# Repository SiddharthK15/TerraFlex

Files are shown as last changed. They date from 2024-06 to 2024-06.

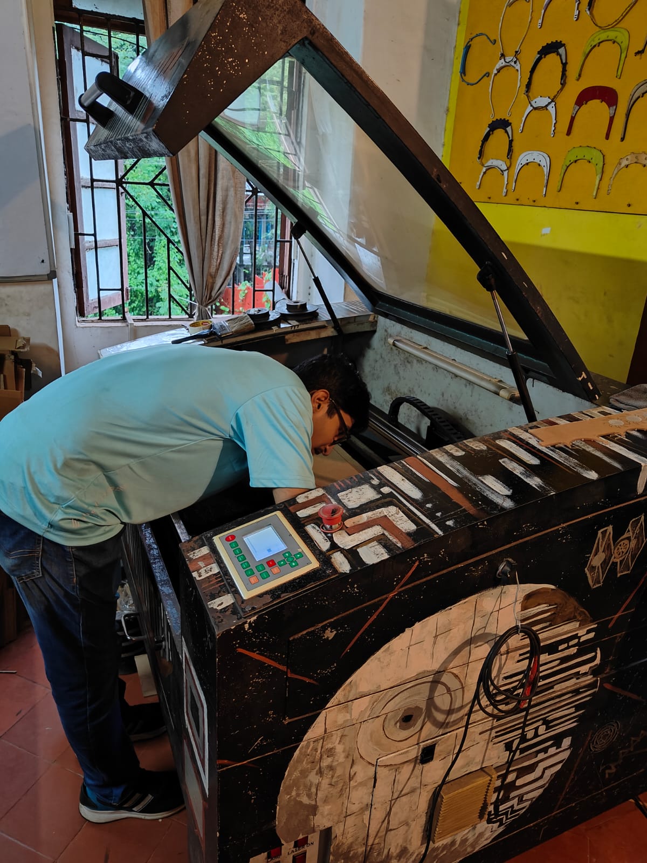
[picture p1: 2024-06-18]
Photos and Videos/Laser Cutting Plywood Testing Track.jpg

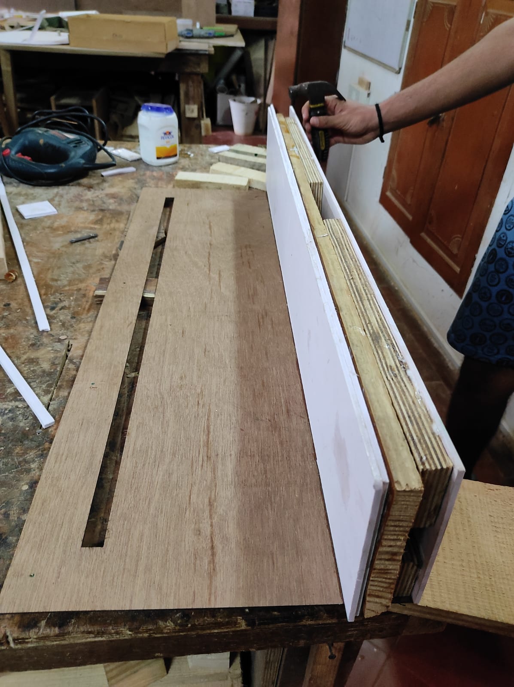
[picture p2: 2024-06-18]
Photos and Videos/Test track_one side.jpg

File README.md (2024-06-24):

Problem statement - Our project introduces an innovative wheel designed to enhance performance across both smooth and rough terrains. Traditional wheels often struggle with stability and traction on uneven surfaces, leading to discomfort and reduced efficiency. 

Solution - Our wheel addresses these challenges by integrating adaptive spring mechanisms that allow the wheel to dynamically adjust to surface irregularities. TerraFlex promises a smoother ride experience while maintaining efficiency on paved roads. 

Objectives - Create a wheel that is equally efficient on smooth roads and rough terrain, Ensure stability by using spring suspensions inside the wheel, as opposed to spokes, Avoid punctures as the wheel is airless

Licensing information

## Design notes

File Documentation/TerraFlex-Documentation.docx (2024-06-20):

Problem statement

Our project introduces an innovative wheel designed to enhance performance across both smooth and rough terrains. Traditional wheels often struggle with stability and traction on uneven surfaces, leading to discomfort and reduced efficiency.

Solution

Our wheel addresses these challenges by integrating spring mechanisms that allow the wheel to dynamically adjust to surface irregularities. TerraFlex provides a smoother experience while maintaining efficiency on paved roads.

Objectives

- Create a wheel that is equally efficient on smooth roads and rough terrain.
- Ensure stability by using spring suspensions inside the wheel, as opposed to spokes.
- Avoid punctures as the wheel is airless

Final Idea

At our 7 day residency at Maker’s Asylum in Goa, we learnt various skills like woodworking, laser cutting and 3D printing. These skills were essential to make the wheel, since our project is purely mechanical with no coding involved.

Our final project is a scale model 150mm diameter wheel with alternating spring and solid sections. The spring sections will absorb any terrain irregularities like rocks and broken ground, and the solid sections will maintain the same regular rotation on smooth roads. Most of the wheel is 3D printed. The 3D printed part sizes can be obtained from the CAD files “Assembly final” or “Wheel made as one.”

Constraints

- The materials used to make the solid sections must be able to withstand the weight of the car, along with jerks during motion.
- The springs must compress adequately to allow smooth motion on rough terrain
- The spring sections must not cause bouncy motion on smooth roads.
- For our prototype, the weight must be accurately simulated as 50-70N

Chronological Progress

Pre-residency (online)

We brainstormed different techniques and mechanisms which can help the wheel maintain stability without having to rely on external vehicle suspension. We took inspiration from the PATS wheel and NASA’s airless wheels for Mars missions. After researching different types of past innovative wheel designs, we decided on creating a wheel with alternating spring sections and solid sections. We designed the CAD models of the wheel on Fusion 360 during online team meetings.

Residential

We designed the testing track to test our wheel prototype on. We finalized on a 850mm length track with a slider and block attached above the wheel to act as the weight of the car. After comparing the ratio of the size of our prototype to the size of an actual wheel, we determined the weight acting on the wheel to be 70N. We then laser-cut the first-version of our bracket for the test track, and cardboard side plates for our side-track and tested the wood block as a slider. After multiple trials, we determined the slider dimensions to be 20mm x 70mm x 18mm. We then got our CAD models 3D printed with ABS, TPU and PLA. We assembled the wheel using super glue to stick the 3D printed parts together. We printed 5 different inner pieces and tested each one of them. We finally decided on using a Large Curve piece. Our final design used 8 solid sections and 8 spring sections with a total of 16 20mm springs.

Materials Used

- 4 x Cylinder - 3D Printed ABS - diameter 30mm and thickness 35mm. With a hole in the middle.
- 24 x Springs - length of 20mm and outer diameter of 10mm. Wire thickness 0.5mm
- 3D printing material - PLA 168g and 109g TPU and 304g ABS
- 850mm x 300mm Plywood with thickness 3mm with a 750mm x 17 mm slit for side plate
- 850mm x 300mm clear acrylic with thickness 1.7mm with a 750mm x 17 mm slit for side plate
- 20mm x 70mm x 160mm Plywood block as slider
- 150mm x 850mm - Sunboard x 2 for base of track

Project Mind Map

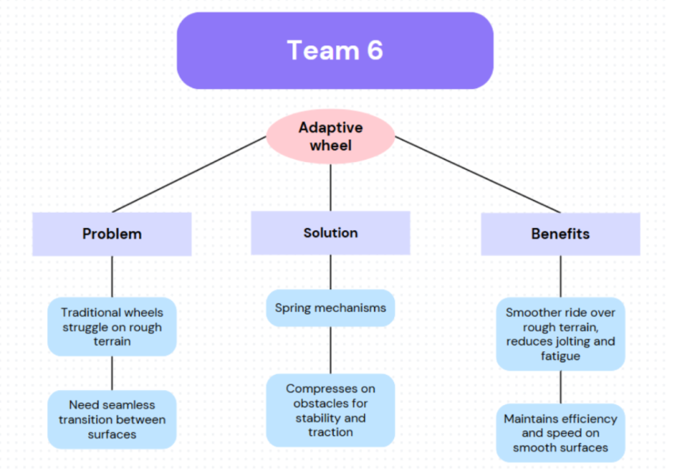
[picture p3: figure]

Block Diagram based on objectives

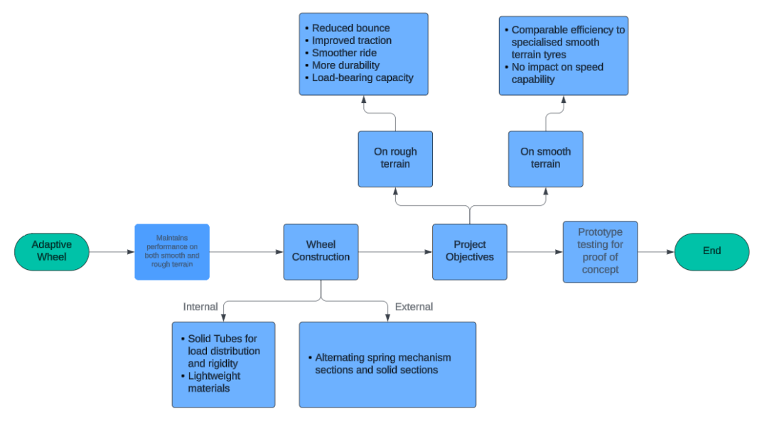
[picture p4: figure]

Final Wheel Model

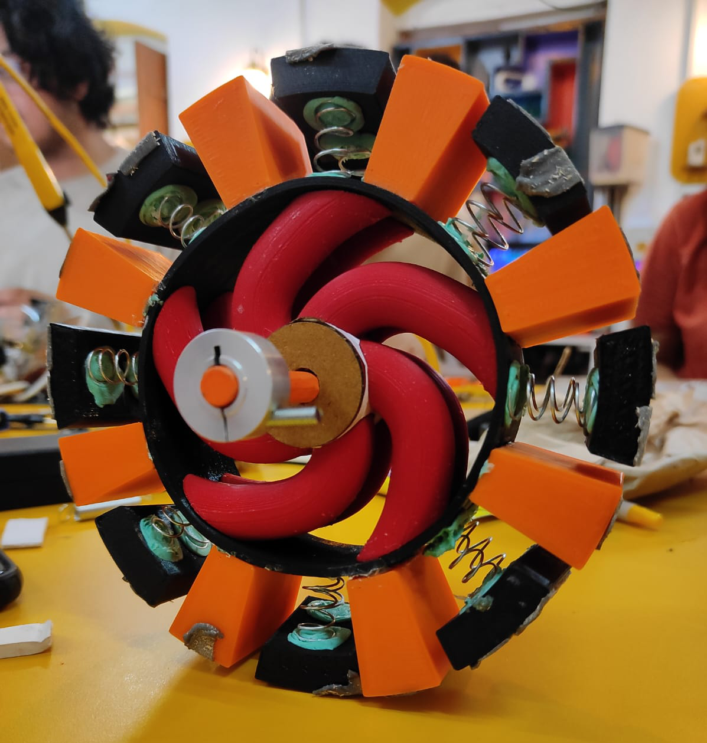
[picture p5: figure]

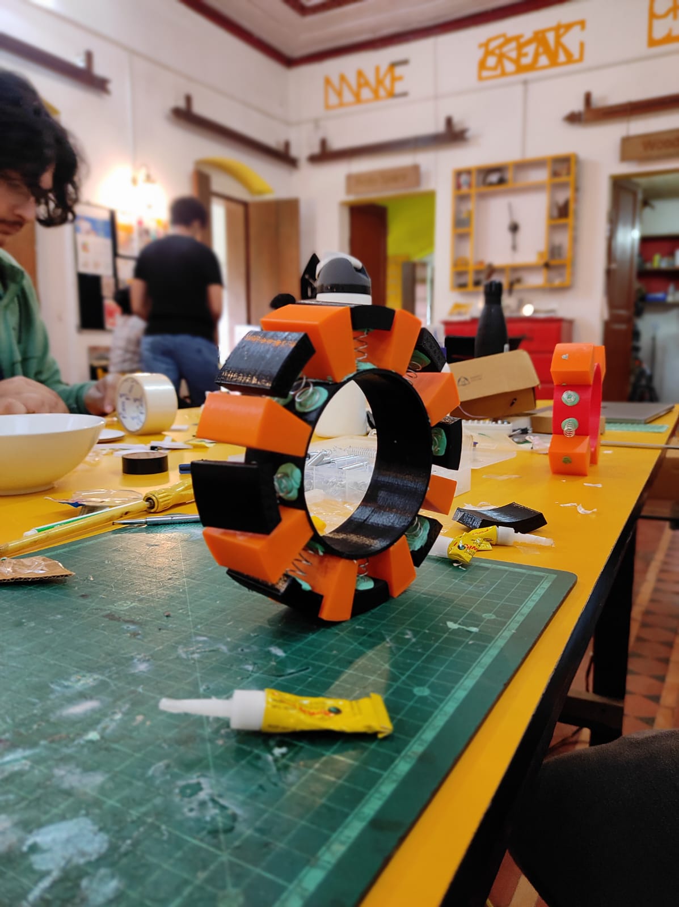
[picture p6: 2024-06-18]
Photos and Videos/Final outer layer.jpg

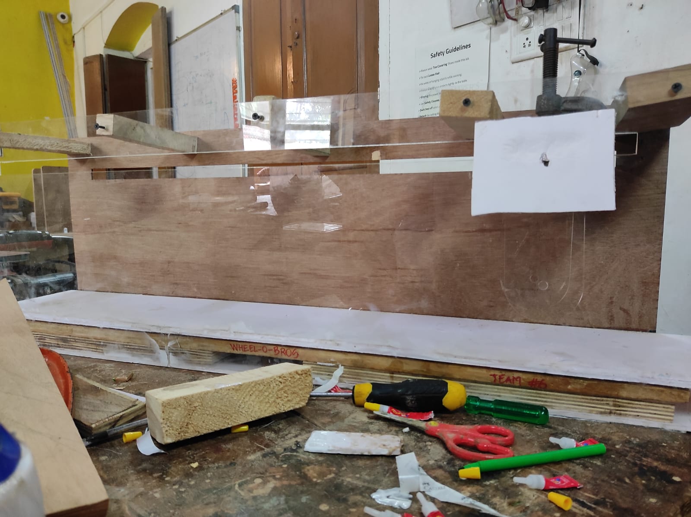
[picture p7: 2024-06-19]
Photos and Videos/Side track final front view.jpg

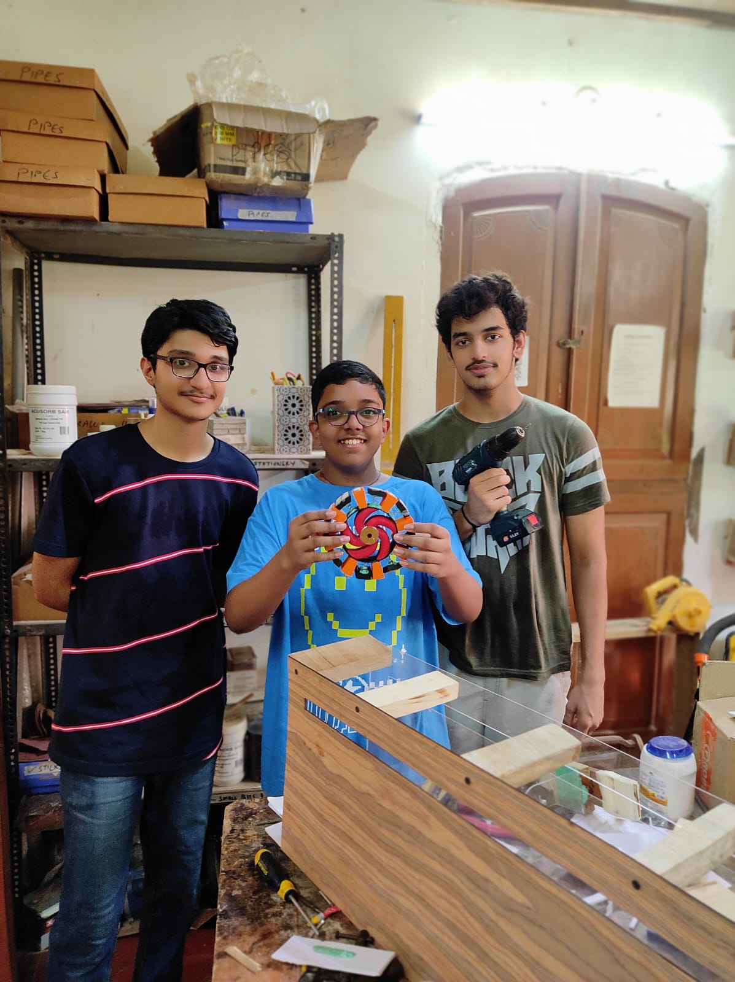
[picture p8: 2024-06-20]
Photos and Videos/Team Photo.jpg

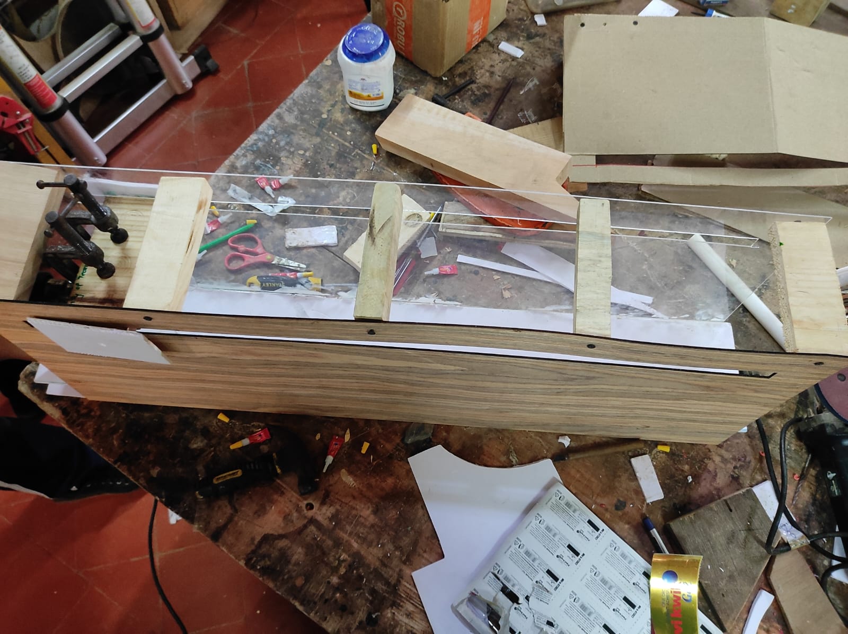
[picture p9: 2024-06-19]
Photos and Videos/Side track final Top view.jpg

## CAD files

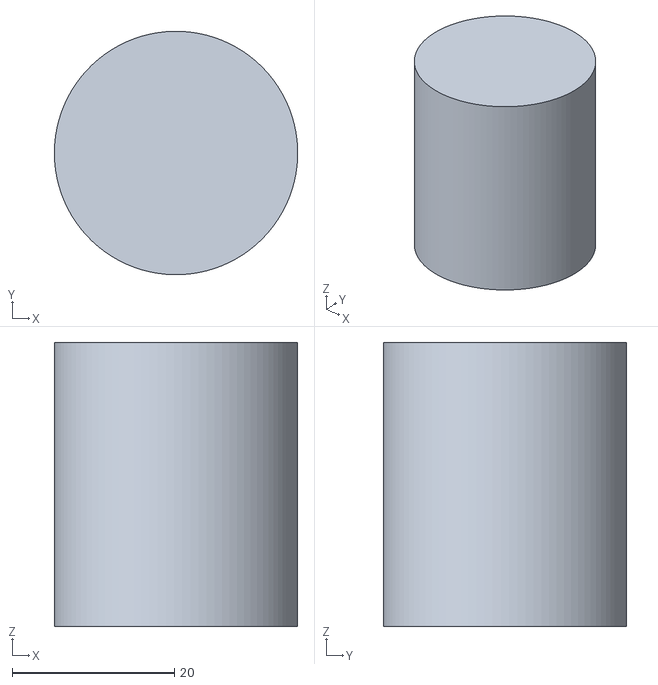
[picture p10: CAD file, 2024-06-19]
CAD/Pin_.stl
30.0 x 30.0 x 35.0

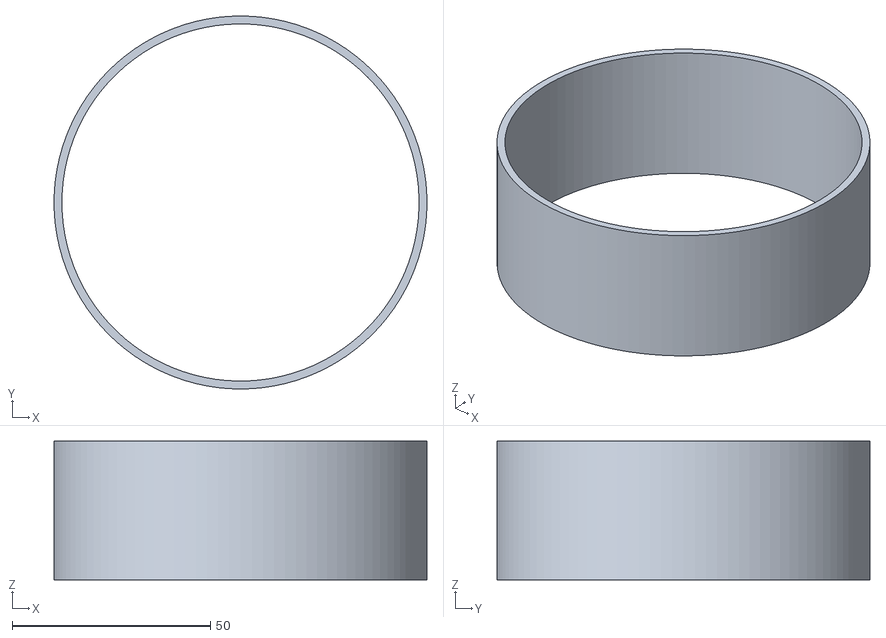
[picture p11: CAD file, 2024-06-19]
CAD/Layer_.stl
94.0 x 94.0 x 35.0

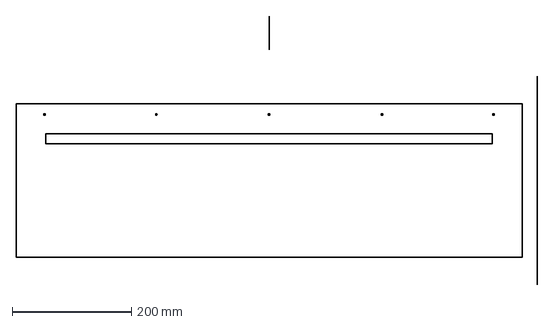
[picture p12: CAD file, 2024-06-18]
CAD/Side track sketch.dxf
875.0 x 451.1 mm

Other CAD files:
CAD/All Tubes v2.f3d
CAD/Center Pin.f3d
CAD/Layer v2.f3d
CAD/OuterLayer_.f3d
CAD/Testing Area_.f3d
CAD/Wheel Made as one_.f3d
